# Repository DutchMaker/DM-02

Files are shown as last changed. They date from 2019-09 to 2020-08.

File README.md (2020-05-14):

# DM-02 8-Bit Computer

_Pronounced: "Dee-Em Zero Two"_

**An 8-bit computer built (almost) entirely out of TTL logic chips**  
This project started in September 2019 and is currently in progress.  
Please refer to the [documentation](./Documentation) for the project status.

**[Start by reading the introduction](./Documentation/)**

If you would like to see the computer in action, the best I can offer you now is the [DM-02 Emulator](https://dutchmaker.com/dm-02/emulator) while the electronic version is under development.

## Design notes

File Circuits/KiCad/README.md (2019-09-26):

# KiCad projects

KiCad EDA is used for all circuit diagrams and PCB design.
Get it for free at: [http://kicad-pcb.org](http://kicad-pcb.org)

### KiCad setup:

- Add `./Libraries/*.lib` as global Symbol library to KiCad (Eeschema)
- Add the `./Libraries` folder as global Footprint library to KiCad (Pcbnew)

### Notes:

- The _FreeRouting_ application (`./Libraries/freeRouting.jar`) is used for initial PCB routing

### Credits:

- Arduino Mega Shield component: https://github.com/Alarm-Siren/arduino-kicad-library
- FreeRouting: https://freerouting.org/

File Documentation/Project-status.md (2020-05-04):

# Project status

This document is here to keep track of the project status. 

## Project log

### 2020-05-01:

Picked up where I left a long time ago. A lot has been done:

- The Logisim circuit is fully functional.
- The microcode language has been specified, all microcode has been written and the microcode compiler is fully functional.
- The assembly language has been specified and the assembler is fully functional
- First example programs run succesfully on the Logisim circuit.

### 2019-10-01:

The Logisim design has all the modules done, except for the Controller. I'll probably build the Microcode Compiler first before starting design of the Controller.

### 2019-09-26:

Started the project log. At this point in the project, countless hours have been put into research and thinking about problems and solutions (related to this computer...). The result of it all has been documented. *Nothing has actually been built yet at this point*.

There will be a bit more documentation work before I start building things. I'm considering using Proteus for simulation instead of Logisim (which I used for DM-01), because it will be easier to simulate the phased clock and it takes propagation delays of IC's into account. 

## Project tasks

The following high-level tasks are waiting to be done (in no particular order):

- Write more documentation as the project progresses.
- Create and maintain the project on Hackaday.
- Circuit design.
- PCB design.

## Project ideas & Reminders

Just some things I need to keep track of:

- Support for interrupts
- Store accumulator and flags register on stack before a CALL instruction (or interrupt) and restore it after RET instruction
- VGA graphics (320x200) with dedicated 64kb VRAM
  - Implement using bank switch (direct access to VRAM from program)?
  - or maybe with I/O commands to a separate gfx module
- All counters need reset lines
- TODO

  - Measure if power + debug board can connect with Arduino in between
  - Update labels on bus connectors for boards bottom, debugger, power/clock
  - Reroute debugger board
    - On assembled board: connect NC3 to SPI_MISO

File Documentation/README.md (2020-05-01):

# DM-02 8-bit Computer

- [Introduction](#introduction)
- [Overall specifications](#overall-specifications)
- [High-level architecture](#high-level-architecture)
- [Documentation](#documentation)
- [Resources](#resources)

## Introduction

The DM-02 (*pronounced: “Dee Em Zero Two”*) is an 8-bit computer built (almost) entirely out of 7400-series (TTL) logic chips. It is the successor to my [74xx Computer](https://github.com/DutchMaker/TTL-computer) which from now on shall be refered to as DM-01.

Why is there a successor to the DM-01? Well, the main reason is that the DM-01 never got to be a fully functional computer. It worked in Logisim, but due to poor design from my end the actual electronics failed to function properly.
The DM-01 was the first computer I designed all by myself and I was learning how to do it while I was doing it. So naturally, mistakes have been made.
I’ve done quite a bit of research since then and decided to give it another go!
Instead of trying to fix the DM-01 I’ve taking all the lessons learned from my first attempt and start from the ground up (although some tooling will be reused).

## Overall specifications
DM-02 is (being) built with the following specifications in mind:

- At least 1 MHz clock speed
- Microcoded control unit
- 8-bit data bus
- 16-bit address bus, allowing for 64 Kb of addressable memory
  - 16 Kb reserved for ROM
  - 48 Kb reserved for RAM *(a 64 Kb RAM chip is used, but only the last 48 Kb can be addressed)*
- 16-bit stack pointer (entire RAM may be used as stack space)
- 16-bit program counter
- Register configuration:
  - 1x 8-bit accumulator (A)
  - 4x 8-bit general purpose registers (B, C, H, L)
  - BC and HL may be used as pair for 16-bit operations
- The ALU is based around an EPROM
- Supported flags: Zero, Carry, Negative, Overflow
- Flags may be pushed/popped onto/off the stack for use in JMP/CALL/RET instructions and for future interrupt support.
- I/O is addressable through memory and there are 256 addresses reserved for this
- Planned I/O modules:
  - Program loader (e.g., from SD card)
  - VGA card
  - Keyboard
- Modular design based on stackable PCBs
- One of these modules is the *Debugger*. This board attaches an Arduino Mega to the DM-02 and allows for:
  - Running hardware tests against each individual module.
  - Simulating the controller module and thus test the interaction between modules.
  - Debug the computer while it’s running programs.

## High-level architecture
The DM-02 architecture is based on a mix of elements found in the 6502, 8085, 6800 and 8088 processor architectures. The following schematic illustrates the high-level architecture of the DM-02.

*Green* lines are 8-bit data bus connections.  
*Red* lines are pairs of 8-bit connections to form a 16-bit value.  
*Orange* lines are 16-bit address lines.  
*Black* lines are internal bus connections.

Architecture overview

## Documentation

Jump to detailed documentation on:

- [Clock signals and timing](./Clock-signals-timing.md)
- [Microcode architecture](./Microcode-architecture.md)
- [Assembly language reference](./Assembly-language.md)
- [ALU and Flags register](./ALU-and-flags.md)
- [Debugger module](./Debugger-module.md)
- [Notes on all the modules](./Modules.md)
- [Logisim instructions](./Logisim-Instructions.md)
- [Project status](./Project-status.md)

## External resources
It’s impossible to refer to every resource that helped me on the way, but a few stand out:

- [Digital Computer Electronics by Malvino & Brown](https://www.amazon.com/Digital-Computer-Electronics-Jerald-Malvino/dp/0074622358) (ISBN: 978-0-07-462235-3); This book has been a treasure of information! A must-have for every CPU enthusiast.
- [Ben Eater’s YouTube videos](https://www.youtube.com/user/eaterbc); His breadboard computer was the first computer I built and his videos are what got me into this whole thing
- [CSCvon8](https://github.com/DoctorWkt/CSCvon8) TTL computer; I've got a lot of inspiration from this project and the ALU ROM is taken from here.
- [Gigatron](http://gigatron.io) TTL computer
- The folks at Hackaday, Reddit and StackEchange

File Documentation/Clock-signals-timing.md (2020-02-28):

# Clock signals and timing

The clock module of the DM-02 generates a 1 MHz clock that is essentially split into two phases (*see: [Clock phases](#clock-phases)*)

There is no option for changing the clock speed (as opposed to the DM-01), but there is a `CONTINUE` function that allows to resume program execution after a `HALT` instruction was executed.

There is also a *single-step mode* that allows the user to manually pulse the clock.

## Clock phases

The 1 MHz clock signal is split into 2 phases: CLOCK1 and CLOCK2.  
CLOCK2 is shifted *120ns* in comparison to CLOCK1 *(see: [Clock timing example](#timing-example))*

When something **output**s to the bus at rising CLOCK1, something else can **load** it at rising CLOCK2. 

The reason for this is that we need to take propagation delays of the logic gates and memory chips into account. For example: let's say that we set the address of our ROM chip and load the data from the chip into a register. In that case it actually takes some time for the data to be available and we have to wait with clocking the register until we know for certain that the data is there.

Propagation delays for most logic gates and registers that we use are 30ns maximum. The ROM chips however have more serious delays:

- W27C512-45Z (Program ROM): 45ns
- M27C1024-10F1 (Microcode ROM): 100ns
- M27C322-100F1 (ALU ROM): 100ns

So when fetching an instruction from memory, once we have set the address of the Microcode ROM, we need to wait 100ns until we can load the data into the Instruction Register.

## Clock timing example

Let's take a look at how the controller fetches and executes an instruction to get a better idea of how the clock phases and timing works.

The instruction we are executing in this example is:

```
MOV A, #$FF    ; Transfer immediate hexadecimal value FF into the A register)
```

The (pseudo) microcode for this instruction looks like this:

```
FETCH:      PC_MAR_transfer  # The fetch cycle is hard-wired in the controller circuit
            IR_load
            MEM_out
            PC_inc

TSTATE_0:   PC_MAR_transfer  # Data micro instruction
            MEM_out	
            A_load
			
TSTATE_1:   PC_inc           # Misc. micro instruction
            TSTATE_reset
```

Now take a look at the clock signals and see when each of the control lines is activated.
The `STATE` changes indicate when the controller changes its state (i.e. what it is currently handling). It will first start the fetch cycle and then cycle through t-states (a.k.a. micro ticks).



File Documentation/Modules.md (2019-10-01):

# DM-02 Modules

*This documentation is still in progress...*

This document contains notes in each of the modules that form the DM-02 Computer.

## Program Counter & Stack Pointer

These two functions share one PCB.

### Program Counter

Built around four 74HCT161 counters. Why different counters than the Stack Pointer? Because a RESET line is required. Also, it does not need to ability to decrement.

### Stack Pointer

*in progress*

## ALU & Flags Register

These share one PCB

### ALU

Changes to the A(ccumulator) register immediately latched into the ALU (A operand).
When ALU_load is high, input for the B operand is loaded from the bus and the result is stored in the A register.
The result is then also latched into the ALU's A operand, within the same clock cycle.

```
# Example microcode for "ADD B"

FETCH: ...
0:     B_out
       ALU_load
       ALU_function=01001
1:     TSTATE_reset
```

### Flags Register

*in progress*

## Memory Access Register & Memory

*in progress*

## Registers

*in progress*

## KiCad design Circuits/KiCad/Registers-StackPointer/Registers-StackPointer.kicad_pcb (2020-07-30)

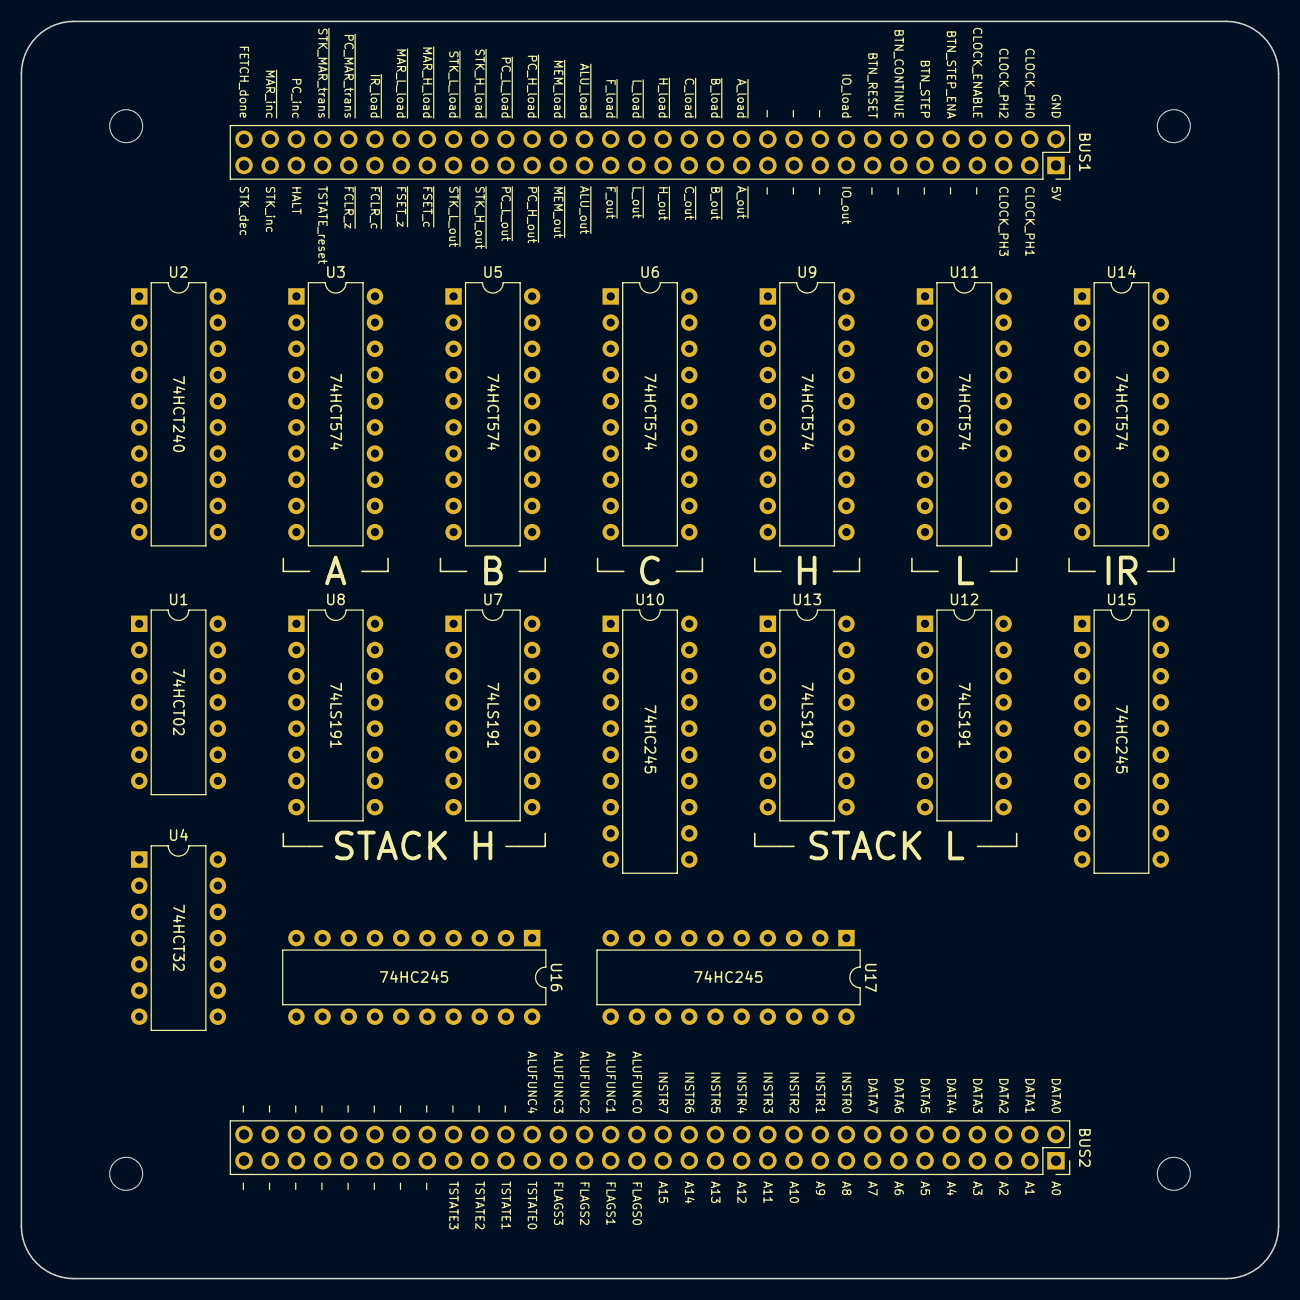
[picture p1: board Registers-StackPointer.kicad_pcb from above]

Board: 2 copper layers, 121.9 x 121.9 mm, 23 parts (0 on the bottom side), 84 nets, no tracks yet.

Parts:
BUS1, BUS2: Conn_02x32_Odd_Even; PinSocket_2x32_P2.54mm_Vertical
H1, H2, H3, H4: MountingHole; MountingHole_3.2mm_M3
U1: 74HCT02; DIP-14_W7.62mm
U2: 74HCT240; DIP-20_W7.62mm
U3, U5, U6, U9, U11, U14: 74HCT574; DIP-20_W7.62mm
U4: 74HCT32; DIP-14_W7.62mm
U7, U8, U12, U13: 74LS191; DIP-16_W7.62mm
U10, U15, U16, U17: 74HC245; DIP-20_W7.62mm

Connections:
5V: BUS1.1, U2.20, U3.20, U5.20, U6.20, U7.16, U8.16, U9.20, U10.20, U11.20, U12.16, U13.16, U14.20, U15.20, U16.20, U17.20
A0: BUS2.1, U17.18
A1: BUS2.3, U17.17
A2: BUS2.5, U17.16
A3: BUS2.7, U17.15
A4: BUS2.9, U17.14
A5: BUS2.11, U17.13
A6: BUS2.13, U17.12
A7: BUS2.15, U17.11
A8: BUS2.17, U16.18
A9: BUS2.19, U16.17
A10: BUS2.21, U16.16
A11: BUS2.23, U16.15
A12: BUS2.25, U16.14
A13: BUS2.27, U16.13
A14: BUS2.29, U16.12
A15: BUS2.31, U16.11
A_clock: U2.18, U3.11
B_clock: U2.16, U5.11
CLOCK_PH3: BUS1.5, U1.11, U1.12, U4.2, U4.4, U12.14
C_clock: U2.14, U6.11
D0: U3.2, U3.19, U5.2, U5.19, U6.2, U6.19, U7.15, U9.2, U9.19, U10.18, U11.2, U11.19, U12.15, U14.2, U15.18
D1: U3.3, U3.18, U5.3, U5.18, U6.3, U6.18, U7.1, U9.3, U9.18, U10.17, U11.3, U11.18, U12.1, U14.3, U15.17
D2: U3.4, U3.17, U5.4, U5.17, U6.4, U6.17, U7.10, U9.4, U9.17, U10.16, U11.4, U11.17, U12.10, U14.4, U15.16
D3: U3.5, U3.16, U5.5, U5.16, U6.5, U6.16, U7.9, U9.5, U9.16, U10.15, U11.5, U11.16, U12.9, U14.5, U15.15
D4: U3.6, U3.15, U5.6, U5.15, U6.6, U6.15, U8.15, U9.6, U9.15, U10.14, U11.6, U11.15, U13.15, U14.6, U15.14
D5: U3.7, U3.14, U5.7, U5.14, U6.7, U6.14, U8.1, U9.7, U9.14, U10.13, U11.7, U11.14, U13.1, U14.7, U15.13
D6: U3.8, U3.13, U5.8, U5.13, U6.8, U6.13, U8.10, U9.8, U9.13, U10.12, U11.8, U11.13, U13.10, U14.8, U15.12
D7: U3.9, U3.12, U5.9, U5.12, U6.9, U6.12, U8.9, U9.9, U9.12, U10.11, U11.9, U11.12, U13.9, U14.9, U15.11
DOWN_~UP: U1.1, U1.5, U7.5, U8.5, U12.5, U13.5
GND: BUS1.2, U2.10, U3.10, U5.10, U6.10, U7.8, U8.8, U9.10, U10.1, U10.10, U11.10, U12.8, U13.8, U14.1, U14.10, U15.1, U15.10, U16.1, U16.10, U17.1, U17.10
HIGH0_Rc: U7.13, U8.14
H_clock: U2.12, U9.11
INSTR0: BUS2.18, U14.19
INSTR1: BUS2.20, U14.18
INSTR2: BUS2.22, U14.17
INSTR3: BUS2.24, U14.16
INSTR4: BUS2.26, U14.15
INSTR5: BUS2.28, U14.14
INSTR6: BUS2.30, U14.13
INSTR7: BUS2.32, U14.12
IR_clock: U2.5, U14.11
LOW0_Rc: U12.13, U13.14
LOW1_Rc: U7.14, U13.13
L_clock: U2.3, U11.11
unnamed: U1.3, U1.4
unnamed: U1.13, U2.1, U2.19
unnamed: U7.3, U10.2, U16.2
unnamed: U7.2, U10.3, U16.3
unnamed: U7.6, U10.4, U16.4
unnamed: U7.7, U10.5, U16.5
unnamed: U8.3, U10.6, U16.6
unnamed: U8.2, U10.7, U16.7
unnamed: U8.6, U10.8, U16.8
unnamed: U8.7, U10.9, U16.9
unnamed: U12.2, U15.3, U17.3
unnamed: U12.3, U15.2, U17.2
unnamed: U12.6, U15.4, U17.4
unnamed: U12.7, U15.5, U17.5
unnamed: U13.2, U15.7, U17.7
unnamed: U13.3, U15.6, U17.6
unnamed: U13.6, U15.8, U17.8
unnamed: U13.7, U15.9, U17.9
STK_dec: BUS1.63, U1.6, U1.9
STK_inc: BUS1.61, U1.2, U1.8
~A_load: BUS1.26, U2.2
~A_out: BUS1.25, U3.1
~B_load: BUS1.28, U2.4
~B_out: BUS1.27, U5.1
~CLK_EN: U1.10, U7.4, U8.4, U12.4, U13.4
~C_load: BUS1.30, U2.6
~C_out: BUS1.29, U6.1
~HIGH_PL: U4.3, U7.11, U8.11
~H_load: BUS1.32, U2.8
~H_out: BUS1.31, U9.1
~IR_load: BUS1.54, U2.15
~LOW_PL: U4.6, U12.11, U13.11
~L_load: BUS1.34, U2.17
~L_out: BUS1.33, U11.1
~STK_H_load: BUS1.46, U4.1
~STK_H_out: BUS1.45, U10.19
~STK_L_load: BUS1.48, U4.5
~STK_L_out: BUS1.47, U15.19
~STK_MAR_transfer: BUS1.58, U16.19, U17.19

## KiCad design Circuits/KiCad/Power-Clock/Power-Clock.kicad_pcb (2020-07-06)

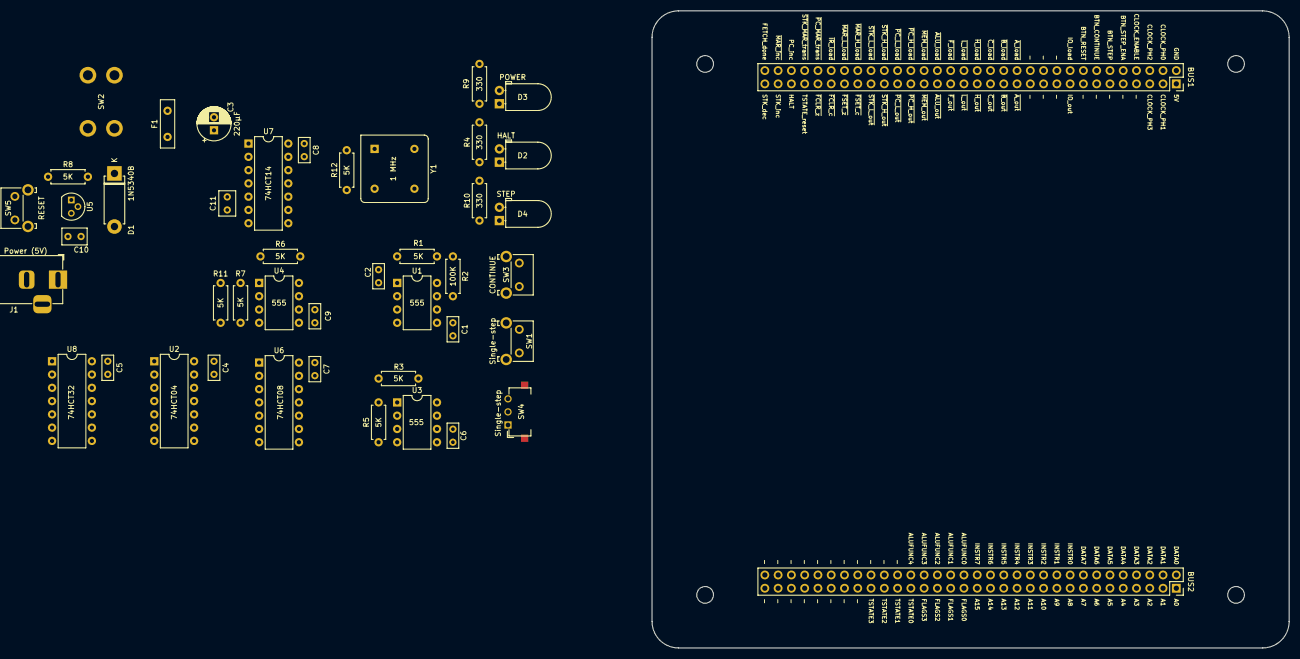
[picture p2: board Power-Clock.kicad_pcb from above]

Board: 2 copper layers, 121.9 x 121.9 mm, 49 parts (0 on the bottom side), 34 nets, no tracks yet.

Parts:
BUS1, BUS2: Conn_02x32_Odd_Even; PinSocket_2x32_P2.54mm_Vertical
C1, C6, C9: 10nF; C_Rect_L4.6mm_W2.0mm_P2.50mm_MKS02_FKP02
C2, C4, C5, C7, C8: 100nF; C_Rect_L4.6mm_W2.0mm_P2.50mm_MKS02_FKP02
C3: 220µF; CP_Radial_D6.3mm_P2.50mm
C10: 100 nF; C_Rect_L4.6mm_W3.0mm_P2.50mm_MKS02_FKP02
C11: 1nF; C_Rect_L4.6mm_W3.0mm_P2.50mm_MKS02_FKP02
D1: 1N5340B; D_5W_P10.16mm_Horizontal
D2: HALT; LED_D5.0mm_Horizontal_O1.27mm_Z3.0mm
D3: POWER; LED_D5.0mm_Horizontal_O1.27mm_Z3.0mm
D4: STEP; LED_D5.0mm_Horizontal_O1.27mm_Z3.0mm
F1: Polyfuse; C_Disc_D9.0mm_W2.5mm_P5.00mm
H1, H2, H3, H4: MountingHole; MountingHole_3.2mm_M3
J1: Power (5V); BarrelJack_Horizontal
R1, R3, R5, R6, R7, R8, R11, R12: 5K; R_Axial_DIN0207_L6.3mm_D2.5mm_P7.62mm_Horizontal
R2: 100K; R_Axial_DIN0207_L6.3mm_D2.5mm_P7.62mm_Horizontal
R4, R9, R10: 330; R_Axial_DIN0207_L6.3mm_D2.5mm_P7.62mm_Horizontal
SW1: Single-step; SW_Tactile_SKHH_Angled
SW2: Power; Switch_DPST_Angled
SW3: CONTINUE; SW_Tactile_SKHH_Angled
SW4: Single-step; Slide-switch
SW5: RESET; SW_Tactile_SKHH_Angled
U1, U3, U4: 555; DIP-8_W7.62mm
U2: 74HCT04; DIP-14_W7.62mm
U5: MCP100-450D; TO-92
U6: 74HCT08; DIP-14_W7.62mm
U7: 74HCT14; DIP-14_W7.62mm
U8: 74HCT32; DIP-14_W7.62mm
Y1: 1 MHz; Oscillator_DIP-8_v2

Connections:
CLK_OSC: U6.5, Y1.3
CLK_STEP: U1.3, U6.1
CLOCK1: U6.11, U7.1, U7.3
CLOCK2: U7.6, U7.9
CLOCK_ENABLE: R12.2, U6.12
COMPUTER_5V: C3.1, C4.1, C5.1, C7.1, C8.1, C10.2, D1.1, F1.1, R1.2, R2.1, R3.2, R5.2, R6.2, R7.2, R8.2, R12.1, SW3.1, U1.4, U1.8, U2.14, U3.8, U4.8, U5.2, U6.14, U7.14, U8.14, Y1.1
COMPUTER_GND: C1.2, C2.2, C3.2, C4.2, C5.2, C6.2, C7.2, C8.2, C9.2, C10.1, C11.1, D1.2, R4.2, R9.1, R10.2, R11.1, SW1.1, SW2.2, SW4.2, SW5.1, U1.1, U2.7, U3.1, U3.6, U4.1, U4.6, U5.3, U6.7, U7.7, U8.7, Y1.2
CONTINUE: SW3.2, U2.1
HALT: D2.2, R7.1, U2.5, U4.4
unnamed: C1.1, U1.5
unnamed: C2.1, R2.2, U1.6, U1.7
unnamed: C6.1, U3.5
unnamed: C9.1, U4.5
unnamed: C11.2, U7.4, U7.5
unnamed: D2.1, R4.1
unnamed: D3.1, R9.2
unnamed: D4.1, R10.1
unnamed: F1.2, SW2.4
unnamed: J1.1, SW2.3
unnamed: J1.2, SW2.1
unnamed: R1.1, SW1.2, U1.2
unnamed: R3.1, SW4.1, U3.2
unnamed: R5.1, SW4.3, U3.4
unnamed: R6.1, U2.2, U4.2
unnamed: R11.2, U4.3, U8.2
unnamed: U2.4, U6.4
unnamed: U2.6, U8.1
unnamed: U6.3, U8.4
unnamed: U6.6, U8.5
unnamed: U6.9, U8.6
unnamed: U6.10, U8.3
unnamed: U6.8, U6.13
STEP_EN: D4.2, U2.3, U3.3, U6.2
~RESET: D3.2, R8.1, SW5.2, U5.1

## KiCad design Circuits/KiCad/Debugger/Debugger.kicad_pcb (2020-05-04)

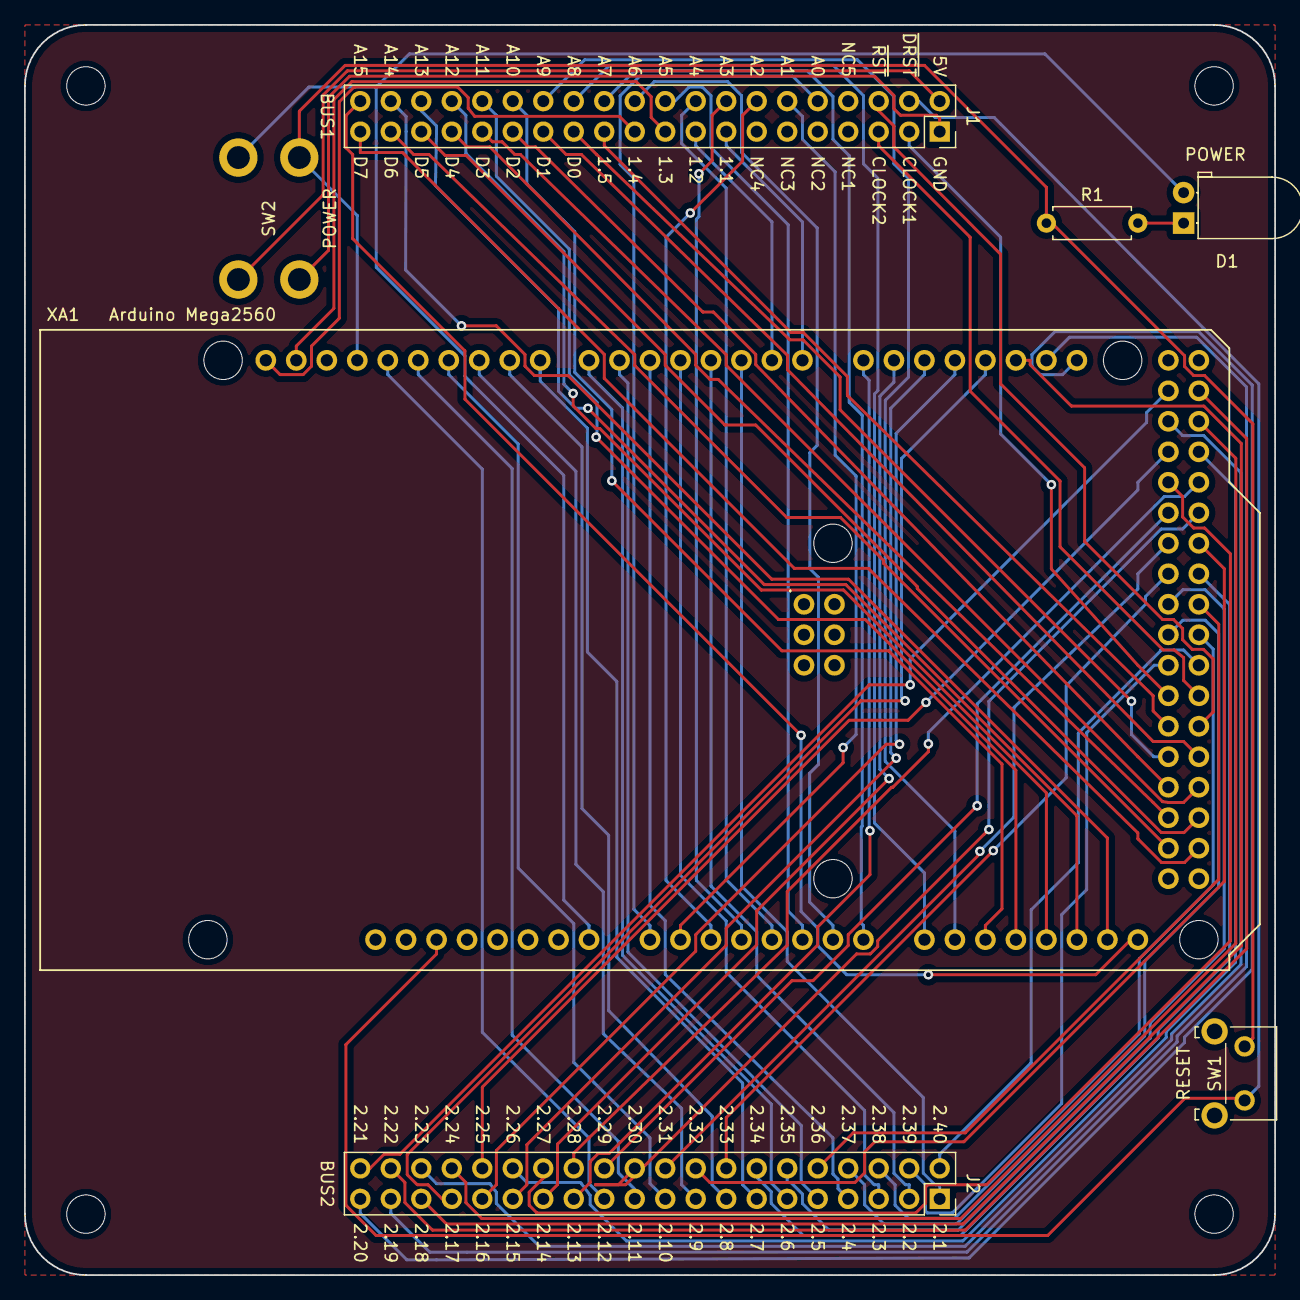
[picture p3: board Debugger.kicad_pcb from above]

Board: 2 copper layers, 104.1 x 104.1 mm, 11 parts (0 on the bottom side), 78 nets.

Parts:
D1: POWER; LED_D5.0mm_Horizontal_O1.27mm_Z3.0mm
H1, H2, H3, H4: MountingHole; MountingHole_3.2mm_M3
J1: BUS1; PinSocket_2x20_P2.54mm_Vertical
J2: BUS2; PinSocket_2x20_P2.54mm_Vertical
R1: 330; R_Axial_DIN0207_L6.3mm_D2.5mm_P7.62mm_Horizontal
SW1: RESET; SW_Tactile_SKHH_Angled
SW2: POWER; Switch_DPST_Angled
XA1: Arduino Mega2560; Arduino_Mega2560_Shield

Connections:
A0: J1.10, XA1.A0
A1: J1.12, XA1.A1
A2: J1.14, XA1.A2
A3: J1.16, XA1.A3
A4: J1.18, XA1.A4
A5: J1.20, XA1.A5
A6: J1.22, XA1.A6
A7: J1.24, XA1.A7
A8: J1.26, XA1.A8
A9: J1.28, XA1.A9
A10: J1.30, XA1.A10
A11: J1.32, XA1.A11
A12: J1.34, XA1.A12
A13: J1.36, XA1.A13
A14: J1.38, XA1.A14
A15: J1.40, XA1.A15
ARDUINO_5V: D1.2, SW2.2, XA1.VIN
ARDUINO_GND: R1.1, SW1.1, SW2.4, XA1.GND1
BUS1_1: J1.15, XA1.D0
BUS1_2: J1.17, XA1.D1
BUS1_3: J1.19, XA1.SDA
BUS1_4: J1.21, XA1.SCL
BUS1_5: J1.23, XA1.D44
BUS2_1: J2.1, XA1.D2
BUS2_2: J2.3, XA1.D3
BUS2_3: J2.5, XA1.D4
BUS2_4: J2.7, XA1.D5
BUS2_5: J2.9, XA1.D6
BUS2_6: J2.11, XA1.D7
BUS2_7: J2.13, XA1.D8
BUS2_8: J2.15, XA1.D9
BUS2_9: J2.17, XA1.D10
BUS2_10: J2.19, XA1.D11
BUS2_11: J2.21, XA1.D12
BUS2_12: J2.23, XA1.D13
BUS2_13: J2.25, XA1.D14
BUS2_14: J2.27, XA1.D15
BUS2_15: J2.29, XA1.D16
BUS2_16: J2.31, XA1.D17
BUS2_17: J2.33, XA1.D18
BUS2_18: J2.35, XA1.D19
BUS2_19: J2.37, XA1.D20
BUS2_20: J2.39, XA1.D21
BUS2_21: J2.40, XA1.D22
BUS2_22: J2.38, XA1.D23
BUS2_23: J2.36, XA1.D24
BUS2_24: J2.34, XA1.D25
BUS2_25: J2.32, XA1.D26
BUS2_26: J2.30, XA1.D27
BUS2_27: J2.28, XA1.D28
BUS2_28: J2.26, XA1.D29
BUS2_29: J2.24, XA1.D30
BUS2_30: J2.22, XA1.D31
BUS2_31: J2.20, XA1.D32
BUS2_32: J2.18, XA1.D33
BUS2_33: J2.16, XA1.D34
BUS2_34: J2.14, XA1.D35
BUS2_35: J2.12, XA1.D36
BUS2_36: J2.10, XA1.D37
BUS2_37: J2.8, XA1.D38
BUS2_38: J2.6, XA1.D39
BUS2_39: J2.4, XA1.D40
BUS2_40: J2.2, XA1.D41
CLOCK1: J1.3, XA1.D42
CLOCK2: J1.5, XA1.D43
COMPUTER_5V: J1.2, SW2.1
COMPUTER_GND: J1.1, SW2.3
D0: J1.25, XA1.D46
D1: J1.27, XA1.D47
D2: J1.29, XA1.D48
D3: J1.31, XA1.D49
D4: J1.33, XA1.D50
D5: J1.35, XA1.D51
D6: J1.37, XA1.D52
D7: J1.39, XA1.D53
unnamed: D1.1, R1.2
~DEBUG_RESET: J1.4, SW1.2, XA1.RST1
~RESET: J1.6, XA1.D45

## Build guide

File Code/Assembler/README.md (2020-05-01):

# DM-02 Assembler

This application is used to compile DM-02 Computer assembly files to DM-02 Computer machine code.
It's a .NET Core application that can compile and run on Windows, macOS and Linux.

## Usage
- Build the application: `dotnet build src`
- Run the application: `dotnet ./src/Asm/bin/Debug/netcoreapp2.2/asm.dll ../Microcode/microcode.src programs/example/example.asm`
- Upload the contents of the `.rom` file into the DM-02's memory.
- The `.img` file can be used as image for the Logisim circuit.

## Shell script
- To use the shell script that assembles the example, just execute: `sh asm.sh`.

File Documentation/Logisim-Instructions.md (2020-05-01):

# Using the Logisim circuit

Just a very short instruction for using the Logisim circuit.

## First time use

1. Latest microcode is already preloaded in the microcode rom.
2. Load the example program image (`example.img`) into the ROM:
   1. Open the Memory circuit.
   2. Right-click the ROM (the top one) and choose *Load Image*...
   3. Select the `example.img` file.
3. Make sure the circuit is reset (Ctrl+R on Windows or ⌘+R on macOS).
4. Set the Tick Frequency to 4.1 Khz
5. Enable the Ticks (Ctrl+K on Windows or ⌘+K on macOS).
6. The program will now execute

## Replacing the microcode

1. Use the microcode compiler to generate new image files based on the `microcode.src` source file.
2. Load the microcode image file into the microcode ROM using the *Load Image* function.

## Running other programs

Simply run the assembler on your own `.asm` files to generate an `.img` file for the program.  
Then load it into the ROM or RAM, like explained with the example.

When running from RAM, please note that a circuit reset will also clear the RAM!
You can perform a soft reset by clicking on the `RESET` button in the top left corner of the main circuit. If you leave `RESET_RAM` set to zero, it will not clear the RAM.

## Debugging

Debugging programs (or the circuit itself) can be quite challenging, but there are a few things in place that may help:

- You can set hardware breakpoints by attaching the `brkpnt0` (up to `brkpnt4`) label to any control line. The computer will then halt when the line goes high.
- You can set software breakpoints by executing the `HALT` instruction.
- You can also manually halt by clicking the `BREAK` button in the top left corner.
- After a halt you can resume execution by clicking the `CONTINUE` button in the top left corner.

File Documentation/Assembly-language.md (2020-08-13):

# Assembly Language

*This documentation is still in progress...*

- [Instruction overview](#instruction-overview)
- [Example code](#example-code)
- [Source file structure](#source-file-structure)
- [Addressing modes](#addressing-modes)
- [Value formats](#value-formats)
- [Memory layout](#memory-layout)
- [Instruction reference](#instruction-reference)

## Instruction overview

The table below briefly describes the instructions that are support by the DM-02 assembly language. Each of the instructions is described in more detail in this document.

| Mnemonic | Description |
| --- | --- |
| [MOV](#MOV) | Transfer data from one location (e.g. register or memory location) to another. |
| [SP](#SP) | Initialize stack pointer |
| [PUSH](#PUSH) | Push data onto the stack |
| [POP](#POP) | Pop data from the stack |
| [ADD](#ADD) | Add to accumulator |
| [ADC](#ADC) | Add to accumulator with carry |
| [SUB](#SUB) | Subtract from accumulator |
| [SBC](#SBC) | Subtract from accumulator with borrow |
| [INC](#INC) | Increment by one |
| [DEC](#DEC) | Decrement by one |
| [AND](#AND) | Logical AND with accumulator |
| [OR](#OR) | Logical OR with accumulator |
| [XOR](#XOR) | Logical XOR with accumulator |
| [NOT](#NOT) | Invert value |
| [SHL](#SHL) | Logical shift left |
| [SHR](#SHR) | Logical shift right |
| [ASR](#ASR) | Arithmetic shift right |
| [ROL](#ROL) | Rotate (carry-over) bits to the left |
| [ROR](#ROR) | Rotate (carry-over) bits to the right |
| [CMP](#CMP) | Compare with accumulator (performs subtraction, but only affect flags) |
| [JMP](#JMP) | Jump program counter to address |
| [JMP](#JMPc) (conditional) | Jump program counter to address if certain condition (flag) applies |
| [CALL](#CALL) | Call a subroutine |
| [CALL](#CALLc) (conditional) | Call a subroutine if certain condition (flag) applies |
| [RET](#RET) | Return from subroutine |
| [RET](#RETc) (conditional) | Return from subroutine if certain condition (flag) applies |
| [FSET](#FSET) | Flag set |
| [FCLR](#FCLR) | Flag clear |
| [NOP](#NOP) | No operation (do nothing) |
| [HALT](#HALT) | Halt program execution |

## Example code

The following piece of example code demonstrates all of the features supported by the assembler (except for every possible instruction).

```
.data																; Data is always stored at the start of memory.
message   : "Hello World"           ; Store string data (automatically terminated with $00).

multiline : "This uses multiple " _ ; An _ is required when a string definition spans
            "lines to define data"  ; multiple lines so the assembler knows to terminate.
            
bytes     : $A4 $FF $5B 'G'         ; Store multiple bytes of data.
            $BC 65 %10001001 $AA    ; data may continue on the next line.
            $AA $BB 
            
buffer    : [1024]                  ; Only define a pointer and reserve space 
                                    ; without predefining the data.
            
*txt_out  : $FF00                   ; Define an address pointer.
                                    ; The * prefix tells the assembler not to apply the 
                                    ; memory offset.
                                    
~maxbyte  : #$FF                    ; Define a constant (simply replaced by the assembler)
~zero     : #0

.include  "example_data.asm"        ; Include the contents of another file.
.offset		$4000											; Define the memory offset (depends on wether the
                                    ; program will run from ROM or RAM).

.code
main:							; The program starts at the 'main' label.
  MOV BC,#message ; Load 16-bit address to the 'message' string into BC register pair.
          
nextchar: 
  MOV A,(BC)      ; Transfer value from memory location HL into A.

  ; Check if we reached the end of the string:
  CMP ~zero       ; Compare A to 0.
  JZ done         ; If A==0 then we reached the string terminator.

  MOV *txt_out,A  ; Transfer value from A to $FF00 (I/O address).

  ; Incrementing a 16-bit register pair:
  INC C           ; First increment the lower byte value.
  MOV A,~zero     ; Load immediate value 0 into A.
  ADC B           ; Add A to B with carry, 
                  ; this increments the higher byte if needed.
  MOV B,A         ; Transfer A to B.
  
  JMP nextchar

done:     
  HALT

.data
example:  "Data may also be stored after the .code block" _
          "Special characters in strings are expressed by their hexadecimal code" _
          "This is a carriage return \0D and this is a tab \09"
```

## Source file structure

Source files must contain one or more blocks of code and may optionally contain one of more data blocks. It may also define a memory offset, which is required if the program needs to execute from RAM:

```
.offset $4000		; memory starts at address hex 4000

.data
  ; this is a data block.
  ; it ends at the next block or end of file...
 
.code
  ; this is the code block (at least one block required)
  ; it ends at the next data block or end of file...
```

### Data blocks

Data blocks are used to predefine data and (at the same time) define address pointer variables and define constants that are replaced by the assembler:

```
.data
pointer_1   : "This is a string " _
              "and we use multiple lines of code " _
              "to define it."

pointer_2   : $41 65 'A' %01000001

pointer_3   : [1024]

pointer_4   : $FF

*pointer_5  : $FF00

~constant_1 : #$FF 
```

The following applies to the example above:

- `pointer_1` stores the bytes contained in the [string](#strings) into memory and stores its location in the pointer.
  For the sake of example, let's say it was stored at address `$4000` (the offset).
  That means that wherever you use `pointer_1` in your code, it will be replaced by `$4000`.

  The length of the string is 64 characters, but the assembler will **automatically add a null terminator** at the end. Therefore it will take up 65 bytes of space!

- `pointer_2` does exactly the same, but it defined the data as explicit bytes. Note how each byte value is [expressed in a different way](#value-formats), but they all are the same value.
  Because the previous defined data took up 65 bytes, `pointer_2` points to `$4041`.

- `pointer_3` only defines a pointer and reserves 1024 bytes of space, but does not define any data. Because the previous defined data took up 5 bytes, `pointer_3` points to `$4046`.

- `pointer_4` is only here as an example to demonstrate what reservering space does. The previous definition (`pointer_3`) reserved 1024 bytes of space and therefore, `pointer_4` points to `$4446`.

- `*pointer_5` refers to the explicit address `$FF00`.

- `~constant_1` will simply be searched/replaced by the assembler. While it makes sense to use it for byte or address values, you could use it for anything - even instructions.

### Code blocks

Code blocks are used to indicate to the assembler that program code definition is about to start:

```
.code
main:					; label main
  MOV A,#$FF	; store 255 in A
  HALT				; halt the processor
```

There may be multiple code blocks defined and they will be processed by the assembler in order of occurrence. This applies when using `.include` to include other files that may contain code.

#### Main label

Programs must contain a `main` label to indicate where program execution starts. This is required because the assembler will add bootloader code at the start of memory that jumps to this label.

### Includes

Other source files may be included by the assembler by refering to their file name:

```
.include "filename.asm"
```

This will include **all** contents of the file at the exact location of the `.include` directive.

### Offset

Because programs may be executed from either ROM or RAM, the assembler needs to know where memory starts:

```
.offset $4000
```

This directive is optional and will default to address zero.

**Note:** the computer uses a 64 Kb RAM chip, but only the last 48 Kb can be addressed by the processor. Therefore RAM program storage starts at address `$4000`.

## Addressing modes

Where DM-01 had many different mnemonics for data transfer, DM-02 mainly uses the `MOV` instruction combined with different addressing modes.

Here are some examples of DM-01 instructions and how they are expressed in the DM-02 assembly language:

| DM-01 instruction | DM-02 instruction |
| --- | --- |
| `MOV A B` | `MOV A,B` |
| `MVI A 0xF8` | `MOV A,#$F8` |
| `MVI B 0xF8`<br />`MVI C 0xA2` | `MOV BC,#$F8A2` |
| `LD A 0xBF46` | `MOV A,$BF46` |
| `ST A 0xBF46` | `MOV $BF46,A` |
| `LDX A 0xBF46` | `MOV A,($BF46)` |
| `LDR A` | `MOV A,(HL)` |

**The DM-02 supports the following explicit addressing modes:**

| Mode | Example notation | Description |
| --- | --- | --- |
| Absolute register | A | Refers to a register to get data from or write data to |
| Absolute register pair | BC | Refers to a register pair (BC or HL) to get data from or write data to |
| Immediate value | #$FF | Defines immediate data |
| Absolute address | $FA6C | Defines a memory address to get data from or write data to |
| Indirect address | ($FA6C) | Defines a memory address, that contains the memory address to get data from or write data to |
| Indirect register | (HL) | Refers to a register pair, that contains the memory address to get data from or write data to |
| *Indexed modes* | *$B47E+A*<br>*($B47E+A)* | _**Currently not supported**, but may be implemented in the future_ |

## Value formats

Values for data may be expressed using different formats:

| Value Type  | Format | Example |
| --- | --- | --- |
| decimal | *value* | `MOV A,#65` |
| hexadecimal | $*value*  | `MOV A,#$41` |
| binary | %*value*  | `MOV A,%1000001` |
| character | '*value*' | `MOV A,#'A'` |
| string | "*value*" | `$4F00: "Hello world"` |

**Note:** 16-bit values (i.e., memory addresses) must always be expressed in hexadecimal format, preferably with all 4 characters to avoid confusion by the assembler (e.g., `$003A`).

### Strings

Defining strings is pretty straight forward as you can see in the example. Some characters require the use of the `\` **escape character** in order to be expressed.

To use an escape character simply write the **2 character** hexadecimal code, prefixed with a backslash:

```
"This is a carriage return: \0D" _
"This is a horizontal tab: \09"
```

If the string definition spans multiple lines, an underscore is required to indicate the string terminator should not be applied.

It must also be noted that the colon (`:`) character is not allowed in string definitions because the assembler uses that character to split the lines. If a string must contain colon, use the `\3A` escape character instead.

## Memory layout

| Start address | End address | Description |
| --- | --- | --- |
| `$0000` | `$3FFF` | ROM (16 Kb) |
| `$4000` | `$FEFF` | RAM (48 Kb) |
| `$FEFF` | `$4000` | Stack space (suggested) |
| `$FF00` | `$FFFF` | I/O |

**Notes:**

- No zero-page addressing support (may be added in future)
- Stack space may start at the end of RAM and works its way back to the start when data is pushed onto it, therefore the entire RAM may technically be used as stack space.
- The starting address of the stack is defined in the program by executing the [SP](#SP) instruction.

### Program storage

The machine code produced by the assembler follows this structure:

1. Bootloader
2. Predefined data
3. Program code

### Bootloader

The assembler adds bootloader code at the start of memory (either address `$0000` or at the offset if it's defined). This code performs a jump to the start of the program code.

This is needed because data that is predefined in the program is stored before any of the instructions.

If a program needs to run from RAM, the bootloader code must be present in the ROM because execution always starts at address zero.

## Instruction reference

### Opcode matrix

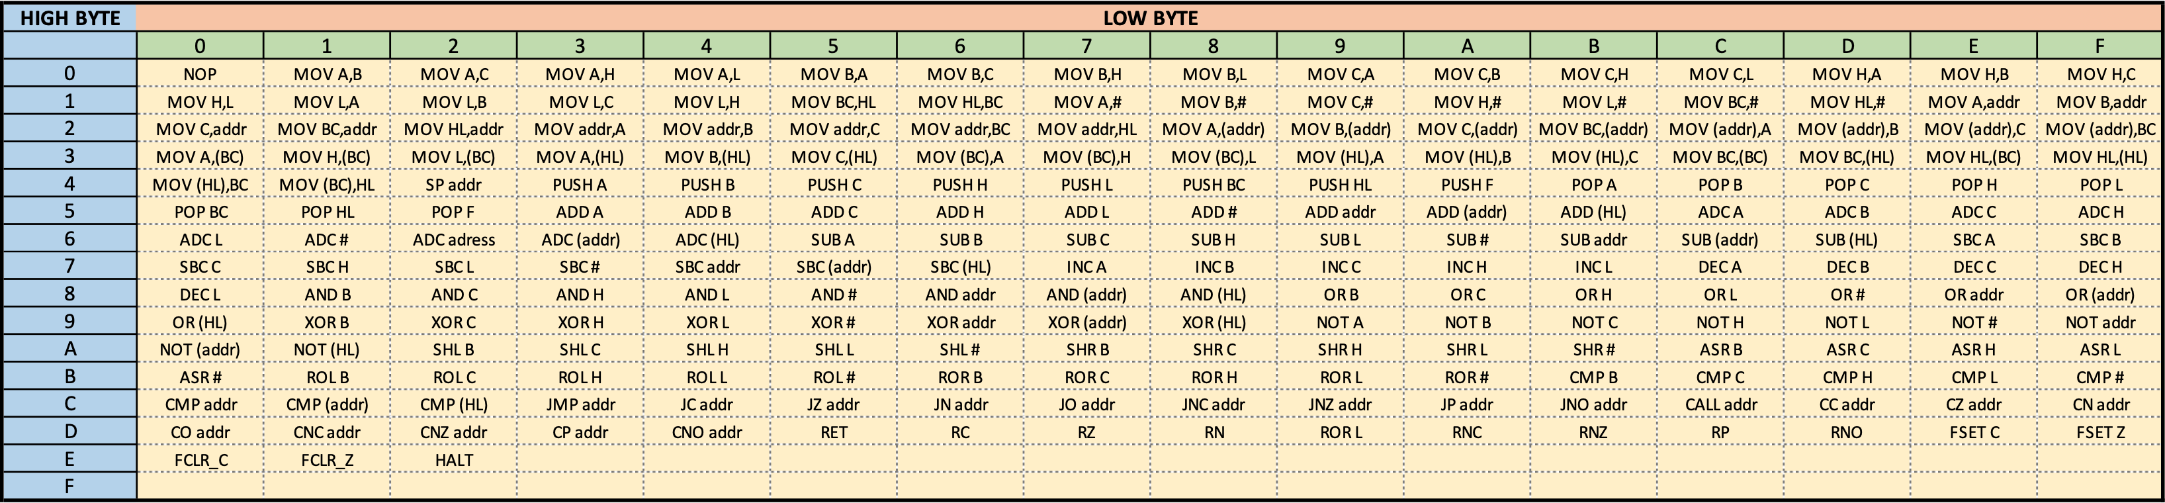
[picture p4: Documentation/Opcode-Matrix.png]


### MOV

|                                     |
| ----------------------------------- |
| MOV A,B                             |
| MOV A,C                             |
| MOV A,H                             |
| MOV A,L                             |
| MOV B,A                             |
| MOV B,C                             |
| MOV B,H                             |
| MOV B,L                             |
| MOV C,A                             |
| MOV C,B                             |
| MOV C,H                             |
| MOV C,L                             |
| MOV H,A                             |
| MOV H,B                             |
| MOV H,C                             |
| MOV H,L                             |
| MOV L,A                             |
| MOV L,B                             |
| MOV L,C                             |
| MOV L,H                             |
| MOV BC,HL                           |
| MOV HL,BC                           |
| MOV A,#$value                       |
| MOV B,#$value                       |
| MOV C,#$value                       |
| MOV H,#$value                       |
| MOV L,#$value                       |
| MOV BC,#$value                      |
| MOV HL,#$value                      |
| MOV A,$address *(overwrites HL)*    |
| MOV B,$address *(overwrites HL)*    |
| MOV C,$address *(overwrites HL)*    |
| MOV BC,$address *(overwrites HL)*   |
| MOV HL,$address                     |
| MOV $address,A *(overwrites HL)*    |
| MOV $address,B *(overwrites HL)*    |
| MOV $address,C *(overwrites HL)*    |
| MOV $address,BC *(overwrites HL)*   |
| MOV $address,HL *(overwrites BC)*   |
| MOV A,($address) *(overwrites HL)*  |
| MOV B,($address) *(overwrites HL)*  |
| MOV C,($address) *(overwrites HL)*  |
| MOV BC,($address) *(overwrites HL)* |
| MOV ($address),A *(overwrites HL)*  |
| MOV ($address),B *(overwrites HL)*  |
| MOV ($address),C *(overwrites HL)*  |
| MOV ($address),BC *(overwrites HL)* |
| MOV A,(BC)                          |
| MOV H,(BC)                          |
| MOV L,(BC)                          |
| MOV A,(HL)                          |
| MOV B,(HL)                          |
| MOV C,(HL)                          |
| MOV (BC),A                          |
| MOV (BC),H                          |
| MOV (BC),L                          |
| MOV (HL),A                          |
| MOV (HL),B                          |
| MOV (HL),C                          |
| MOV BC,(HL)                         |
| MOV HL,(BC)                         |
| MOV (HL),BC                         |
| MOV (BC),HL                         |

### SP

|             |
| ----------- |
| SP $address |

### PUSH

| *Requires SP to be executed first* |
| ---------------------------------- |
| PUSH A                             |
| PUSH B                             |
| PUSH C                             |
| PUSH H                             |
| PUSH L                             |
| PUSH BC                            |
| PUSH HL                            |
| PUSH F                             |

### POP

| *Requires PUSH to be executed first* |
| ------------------------------------ |
| POP A                                |
| POP B                                |
| POP C                                |
| POP H                                |
| POP L                                |
| POP BC                               |
| POP HL                               |
| POP F                                |

### ADD

|                                  |
| -------------------------------- |
| ADD A                            |
| ADD B                            |
| ADD C                            |
| ADD H                            |
| ADD L                            |
| ADD #$value                      |
| ADD $address *(overwrites HL)*   |
| ADD ($address) *(overwrites HL)* |
| ADD (HL)                         |

### ADC

|                                  |
| -------------------------------- |
| ADC A                            |
| ADC B                            |
| ADC C                            |
| ADC H                            |
| ADC L                            |
| ADC #$value                      |
| ADC $address *(overwrites HL)*   |
| ADC ($address) *(overwrites HL)* |
| ADC (HL)                         |

### SUB

|                                  |
| -------------------------------- |
| SUB A                            |
| SUB B                            |
| SUB C                            |
| SUB H                            |
| SUB L                            |
| SUB #$value                      |
| SUB $address *(overwrites HL)*   |
| SUB ($address) *(overwrites HL)* |
| SUB (HL)                         |

### SBC

|                                  |
| -------------------------------- |
| SBC A                            |
| SBC B                            |
| SBC C                            |
| SBC H                            |
| SBC L                            |
| SBC #$value                      |
| SBC $address *(overwrites HL)*   |
| SBC ($address) *(overwrites HL)* |
| SBC (HL)                         |

### INC

*Sets zero flag* if >255

|          |
| -------- |
| INC A    |
| *INC B*  |
| *INC C*  |
| *INC H*  |
| *INC L*  |
| *INC BC* |
| *INC HL* |

### DEC

*Sets negative flag* if <0

|          |
| -------- |
| DEC A    |
| *DEC B*  |
| *DEC C*  |
| *DEC H*  |
| *DEC L*  |
| *DEC BC* |
| *DEC HL* |

### AND

|                  |
| ---------------- |
| AND B            |
| AND C            |
| AND H            |
| AND L            |
| *AND #$value*    |
| *AND $address*   |
| *AND ($address)* |
| *AND (HL)*       |

### OR

|                 |
| --------------- |
| OR B            |
| OR C            |
| OR H            |
| OR L            |
| *OR #$value*    |
| *OR $address*   |
| *OR ($address)* |
| *OR (HL)*       |

### XOR

|                  |
| ---------------- |
| XOR B            |
| XOR C            |
| XOR H            |
| XOR L            |
| *XOR #$value*    |
| *XOR $address*   |
| *XOR ($address)* |
| *XOR (HL)*       |

### NOT

|                                               |
| --------------------------------------------- |
| NOT A                                         |
| NOT B *(affects register it is performed on)* |
| NOT C *(affects register it is performed on)* |
| NOT H *(affects register it is performed on)* |
| NOT L *(affects register it is performed on)* |
| *NOT #$value*                                 |
| *NOT $address*                                |
| *NOT ($address)*                              |
| *NOT (HL)*                                    |

### SHL

|                                               |
| --------------------------------------------- |
| SHL A                                         |
| SHL B |
| SHL C |
| SHL H |
| SHL L |
| *SHL #$value*                                 |

### SHR

|                                               |
| --------------------------------------------- |
| SHR B |
| SHR C |
| SHR H |
| SHR L  |
| *SHR #$value*                                 |

### ASR

|                                               |
| --------------------------------------------- |
| ASR B |
| ASR C |
| ASR H |
| ASR L  |
| *ASR #$value*                                 |

### ROL

|                  |
| ---------------- |
| ROL B            |
| ROL C            |
| ROL H            |
| ROL L            |
| *ROL #$value*    |

### ROR

|                  |
| ---------------- |
| ROR B            |
| ROR C            |
| ROR H            |
| ROR L            |
| *ROR #$value*    |

### CMP

|                  |
| ---------------- |
| CMP B            |
| CMP C            |
| CMP H            |
| CMP L            |
| *CMP #$value*    |
| *CMP $address*   |
| *CMP ($address)* |
| *CMP (HL)*       |

Compare result:

|Carry|Zero|Meaning|
|-|-|-|
| 1 | 0 | A < B |
| 0 | 1 | A == B |
| 0 | 0 | A > B |

### JMP

### JMP (conditional)

|              |
| ------------ |
| JC $address  |
| JZ $address  |
| JN $address  |
| JO $address  |
| JNC $address |
| JNZ $address |
| JP $address  |
| JNO $address |

### CALL

### CALL (conditional)

|              |
| ------------ |
| CC $address  |
| CZ $address  |
| CN $address  |
| CO $address  |
| CNC $address |
| CNZ $address |
| CP $address  |
| CNO $address |

### RET

*Check for use within label*

### RET (conditional)

|      |
| ---- |
| RC   |
| RZ   |
| RN   |
| RO   |
| RNC  |
| RNZ  |
| RP   |
| RNO  |

### FSET

|        |
| ------ |
| FSET C |
| FSET Z |

### FCLR

|        |
| ------ |
| FCLR C |
| FCLR Z |

### NOP

### HALT

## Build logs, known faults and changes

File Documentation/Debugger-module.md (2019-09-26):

# Debugger module

*This documentation is still in progress...*

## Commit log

2019-10-03 Working on decoding circuit
2020-02-29 Testing new fetch cycle circuit
2020-04-15 Updated PCB for Bottom and Debugger (sent to manufacturer)
    [Bottom-Plate-B.Cu.gbl, Bottom-Plate-B.Mask.gbs, Bottom-Plate-B.Paste.gbp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]
2020-04-16 Working out clock module
    [Power-Clock.sch]
2020-04-18 Updated clock circuit
    [Power-Clock.sch]
2020-04-18 Tested clock circuit
    [Power-Clock.sch]
2020-04-18 Footprint fix switch
    [Power-Clock.sch]
2020-04-21 Routed power & clock PCB
    [Debugger.kicad_pcb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]
2020-04-24 Attempt to improve Logisim circuit
    [Registers.kicad_pcb, Registers.sch]
2020-04-26 Improving logisim circuit
2020-04-27 Implemented MAR_inc in Logisim circuit
2020-04-28 Fixed program counter bug and implemented flags pop
    [Registers.sch]
2020-04-28 Doing some restructuring of the Logisim circuit
2020-04-28 Restructuring Logisim circuit
2020-04-28 Work in progress on assembler
2020-04-29 Finished the assembler and got the example program running in Logisim!
2020-04-30 Fixed assembler bug to resolved instructions incorrectly
2020-05-01 Added breakpoint handler to Logisim circuit
2020-05-01 Fixed issue with offset. Added reset logic to circuit
2020-05-01 Assembler now displays pointer variables in output
2020-05-04 Ditched work on the emulator in dotnetcore and started building one in javascript with web interface
    [Debugger.sch, Power-Clock.sch, Registers-StackPointer.kicad_pcb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]
2020-05-19 Figuring out bus connections
    [PCB-Bus-Connections.xlsx]
2020-06-29 Updated bus connections and bottom plate design
    [Bottom-Plate.kicad_pcb, Bottom-Plate.sch, PCB-Bus-Connections.xlsx]
2020-07-13 Register/stack schematic & PCB
    [Bus-Connectors.sch, Registers-StackPointer.dsn, Registers-StackPointer.kicad_pcb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]
2020-07-30 Did a bit of work on circuit design
    [ALU.kicad_pcb, ALU.sch, Registers-StackPointer.kicad_pcb]
2020-08-13 Working on memory circuit design
    [Memory.kicad_pcb, Memory.sch, Registers-StackPointer.sch]
2020-08-14 Memory circuit
    [Memory.sch]
